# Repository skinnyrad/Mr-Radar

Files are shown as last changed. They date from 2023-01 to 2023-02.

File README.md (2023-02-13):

# Mr Radar
Mr. Radar is a port security evading, discovery device used to detect network switches connected to lone network ports. In addition, it has the ability to detect if Power over Ethernet (PoE) is present and whether the PoE being provide is Mode A or Mode B in nature. An understanding of the functionality of Mr. Radar can be found here: https://skinnyrd.com/mr-radar-layer-1-recon/

Mr Radar Photo

Mr. Radar has the following indicators that appear on the Trinket M0.
- Small Green LED: Mr. Radar is ON. LED is located to the left of the µUSB connector.
- Large Green LED: Mr. Radar has discovered a network device. LED is the Dotstar in the center.
- Large Orange LED: Mr. Radar has discovered a network device that can only support 10/100 Mbits/s. LED is the Dotstar in the center.
- Small Rapid Blinking Red LED: Mr. Radar has detected PoE in a Mode A configuration. LED is located to the right of the µUSB connector.
- Small Slowly Blinking Red LED: Mr. Radar has detected PoE in a Mode B configuration. LED is located to the right of the µUSB connector.

## Github File Structure
The hardware folder contains the KiCad project files for Mr. Radar. The MrRadar_firmware folder contains the .ino file for the Arduino IDE. These files will be used to program the Trinket M0 which controls Mr. Radar.

## Schematic
If you don't want to bother with KiCad and just want to make the board from scratch or want to use another microcontroller, the schematic below will help.
mrradarschematic

## Bill of Materials
- J1: [RJ-45 Connector](https://www.digikey.com/short/mw80n14h)
- R1: 100kΩ 1/4W
- R2: 100kΩ 1/4W
- R3: 10kΩ 1/4W
- R4: 10kΩ 1/4W
- R5: 10kΩ 1/4W
- R6: 3.3kΩ 1/4W
- R7: 10kΩ 1/4W
- R8: 100kΩ 1/4W
- R9: 100kΩ 1/4W
- U1: [Trinket M0](https://www.adafruit.com/product/3500)
- SW1: [SPST Switch](https://www.digikey.com/short/q5dbrt7p)
- BT1: [Battery Pack](https://www.digikey.com/short/m8dprrz4)
- 2 Machine Screws: [#2-56 Thread Size, 1/4 in Lg, 18-8](https://www.grainger.com/product/GRAINGER-APPROVED-Machine-Screw-2-56-Thread-1ZB23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)
- 2 Hex Nuts: [Plain, 18-8, Stainless Steel, #2-56 Thread](https://www.grainger.com/product/GRAINGER-APPROVED-Hex-Nut-Plain-1WA81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)

## Tips for construction
- When loading the code for the Trinket M0, ensure you have setup the Trinket according to the [Adafruit tutorial](https://learn.adafruit.com/adafruit-trinket-m0-circuitpython-arduino). Use the Arduino IDE setup procedures.
- The battery pack goes on the bottom of the board. You'll need to solder everything on top first and then clip all the excess wire pieces before affixing the battery pack.

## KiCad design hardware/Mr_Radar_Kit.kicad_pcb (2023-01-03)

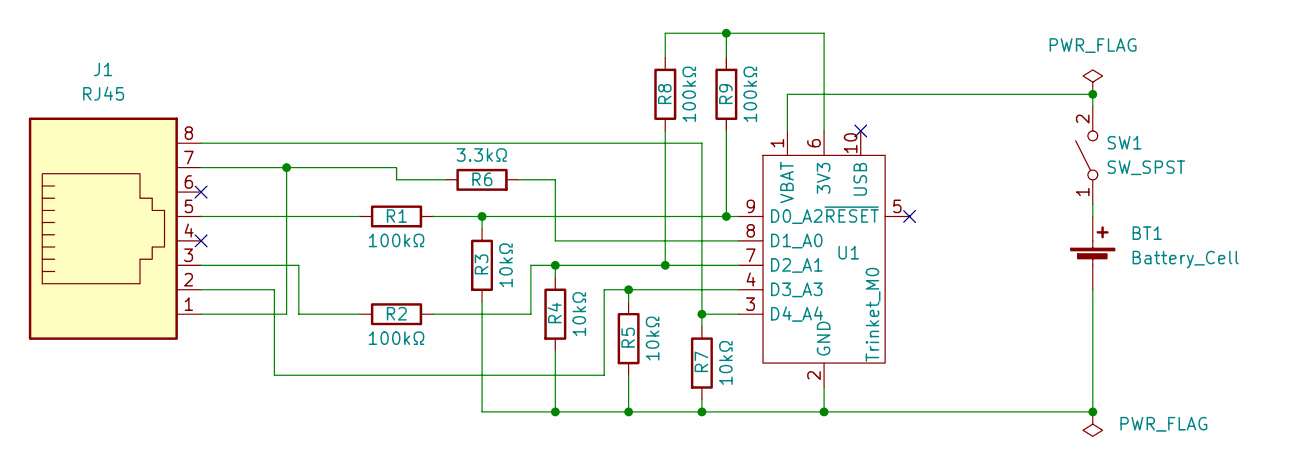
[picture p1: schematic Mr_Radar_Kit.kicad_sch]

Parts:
BT1: Battery_Cell; AAA_Keystone_2479
J1: RJ45; RJ45_RJSSE-5080
R1, R2, R8, R9: 100kΩ; R_Axial_DIN0207_L6.3mm_D2.5mm_P10.16mm_Horizontal
R3, R4, R5, R7: 10kΩ; R_Axial_DIN0207_L6.3mm_D2.5mm_P10.16mm_Horizontal
R6: 3.3kΩ; R_Axial_DIN0207_L6.3mm_D2.5mm_P10.16mm_Horizontal
SW1: SW_SPST; SW_DIP_SPSTx01_Slide_9.78x4.72mm_W7.62mm_P2.54mm
U1: Trinket_M0; Trinket M0

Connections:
unnamed: BT1.1 (+), SW1.1 (A)
unnamed: BT1.2 (-), R3.2, R4.2, R5.2, R7.2, U1.2 (GND)
unnamed: J1.1, J1.7, R6.1
unnamed: J1.2, R5.1, U1.4 (D3_A3)
unnamed: J1.3, R2.1
unnamed: J1.5, R1.1
unnamed: J1.8, R7.1, U1.3 (D4_A4)
unnamed: R1.2, R3.1, R9.1, U1.9 (D0_A2)
unnamed: R2.2, R4.1, R8.1, U1.7 (D2_A1)
unnamed: R6.2, U1.8 (D1_A0)
unnamed: SW1.2 (B), U1.1 (VBAT)
unnamed: R8.2, R9.2, U1.6 (3V3)

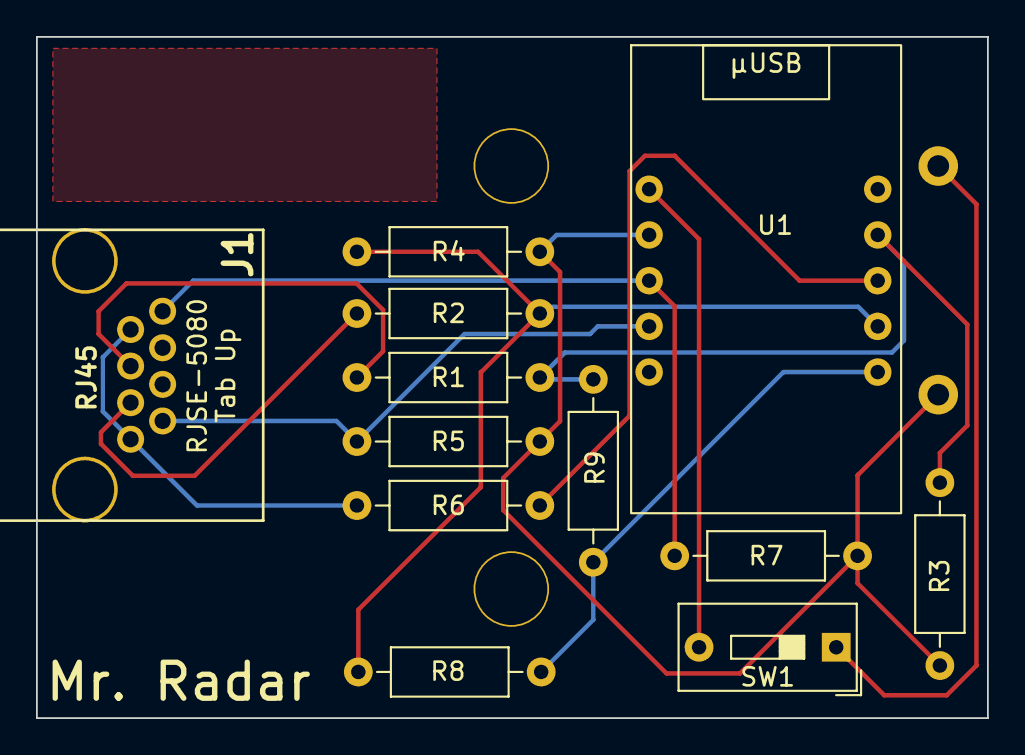
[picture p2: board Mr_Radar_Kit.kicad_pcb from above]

Board: 2 copper layers, 52.8 x 37.8 mm, 13 parts (1 on the bottom side), 12 nets.

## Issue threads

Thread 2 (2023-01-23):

Versions 1.2.0+ breaks onboard DotStar on Trinket M0

boredgamesdev, 2023-01-23:
This active issue on Github [](https://github.com/adafruit/Adafruit_DotStar/issues/52) causes errors on this project. Makes sure to use 1.1.5 version which can be selected from the Arduino IDE install dropdown.

skinnyrad, 2023-01-24:
Thanks for pointing this out. I'll check in occasionally to see if Adafruit corrects the issue. Until then 1.1.5 it will be.

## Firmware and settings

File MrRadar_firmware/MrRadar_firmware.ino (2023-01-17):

#include <Adafruit_DotStar.h>

//Defining pins for the RGB Led on board the trinket
#define NUMPIXELS 1 
#define DATAPIN 7
#define CLOCKPIN 8

//Setup for the RGB Led
Adafruit_DotStar strip = Adafruit_DotStar(NUMPIXELS, DATAPIN, CLOCKPIN, DOTSTAR_BGR);

//Define the pins on trinket to read voltages
int ModeA = 1;  //Analog Pin 1
int ModeB = 2;  //Analog Pin 2
int Pair2 = 3;  //Analog Pin 3
int Pair4 = 4;  //Analog Pin 4

//Initialize the voltage values
int ModeA_val = 0;
int ModeB_val = 0;
int Pair2_val = 0;
int Pair4_val = 0;

void setup()
{
  //Start RGB Led
  strip.begin();
  strip.show();

  //Start a serial connection for debugging
  Serial.begin(9600);

  //Initialize Red LED
  pinMode(13, OUTPUT);  //Digital Pin 13 is an LED on the Trinket M0

  //Power feed for Resistance measurement
  pinMode(1,OUTPUT);  //Digital Pin 1 is the same as Analog Pin 0.
                      //pinMode is a function for digital Pins so we use 1
}

void loop()
{
  //Read voltages on each pin for PoE
  ModeA_val = analogRead(ModeA);
  ModeB_val = analogRead(ModeB);
  //End PoE Readings

  //Turn on voltage for resistance reading
  digitalWrite(1, HIGH);          //Turn on digital Pin 1 to create a voltage on the line        
  delay(150);                     //Provide enough time for the line to achieve steady state
  Pair2_val = analogRead(Pair2);  //Read voltage on Pair 2
  Pair4_val = analogRead(Pair4);  //Read voltage on Pair 4
  
  //Turn off voltage for resistance reading
  digitalWrite(1, LOW);           
  delay(150);

  //Display those voltages across serial link for debugging
  //Values will be between 0 and 1024. 
  Serial.print("Mode A: ");
  Serial.print(ModeA_val);
  Serial.println(" ");
  Serial.print("Mode B: ");
  Serial.print(ModeB_val);
  Serial.println(" ");
  Serial.print("Pair 2 present? ");
  Serial.print(Pair2_val);
  Serial.println(" ");
  Serial.print("Pair 4 present? ");
  Serial.print(Pair4_val);
  Serial.println(" ");
  Serial.println(" ");
  Serial.println(" ");

  //If Pair 2 and Pair 4 are both connected to a transformer then
  //cause the RGB LED to go green.
  if((Pair2_val>150)&&(Pair4_val>150))
  {
    strip.setPixelColor(0, 0x00FF00); // green
    strip.show();
  }
  //If Pair 2 is connected, but Pair 4 is not connected to a transformer then
  //cause the RGB LED to go orange.
  else if((Pair2_val>150)&&(Pair4_val<150))
  {
    strip.setPixelColor(0, 255,165,0); // orange
    strip.show();
  }
  //If neither pair is connected, turn off the RGB LED.
  else
  {
    strip.clear();
    strip.show();
  }

  //If voltage is present on pair 3, then blink red LED fast.
  if(ModeA_val>100 || ModeA_val<80)
  {
    digitalWrite(13, HIGH);
    delay(50);
    digitalWrite(13, LOW);
    delay(50);
    digitalWrite(13, HIGH);
    delay(50);
    digitalWrite(13, LOW);
    delay(50);   
    digitalWrite(13, HIGH);
    delay(50);
    digitalWrite(13, LOW);
    delay(50);
    digitalWrite(13, HIGH);                           
  }
  //If voltage is present on pair 1, then blink red LED slow.
  else if(ModeB_val>100 || ModeB_val<80)
  {
    digitalWrite(13, HIGH);
    delay(300);
    digitalWrite(13, LOW);
    delay(300);
    digitalWrite(13, HIGH);
    delay(300);
    digitalWrite(13, LOW);
  }
  //If no voltage is present, darken the LED.
  else
  {
    digitalWrite(13, LOW);
  }
  delay(1000);
}

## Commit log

2023-01-03 initial upload
    [Mr_Radar_Kit-B_Cu.gbr, Mr_Radar_Kit-B_Mask.gbr, Mr_Radar_Kit-B_Paste.gbr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]
2023-01-16 Update README.md
    Added a schematic to the README
2023-02-13 Update README.md
    Updated BOM
